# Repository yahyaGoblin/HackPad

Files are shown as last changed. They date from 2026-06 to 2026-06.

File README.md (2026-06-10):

# HACKPAD
A compact 4-key macropad powered by the Seeed XIAO, with a rotary encoder for volume, scroll, or whatever feels useful that week. Fully custom PCB, hand-routed, with MX-compatible switch footprints at 19.05mm spacing.
This was the project that started everything — a Hack Club Hackpad build that turned into a crash course in KiCad, footprint libraries, PCB layout, and knowing when to scale back (and when not to). It taught the fundamentals that every later project relied on.

### Schematic Preview


### PCB Preview


### 3D Model


## Features
- 4 mechanical key switches
- 1 rotary encoder (clicky, EC11)
- Seeed XIAO MCU (small footprint, USB-C)
- Compact single PCB design

### Bill of Materials
| Component | Part | Quantity | Notes | Link | Distributor |
|---|---|---|---|---|---|
| Microcontroller | Seeed XIAO RP2040 | 1 | | [Link](https://keebd.com/products/xiao-rp2040-controller?_pos=1&_psq=xiao&_ss=e&_v=1.0) | KEEBD |
| Switches | MX-compatible mechanical switches (Gateron Blue) | 4 | 5-pin or 3-pin | [Link](https://keebd.com/products/gateron-blue) | KEEBD |
| Keycaps | MX keycaps | 4 | | — | local |
| Rotary Encoder | EC11 rotary encoder | 1 | With push switch | [Link](https://keebd.com/products/ec11-encoder-with-switch?_pos=1&_psq=enco&_ss=e&_v=1.0) | KEEBD |
| Encoder Knob | 3D Printed EC11-compatible knob | 1 | | [Link](https://keebd.com/products/3d-printed-encoder-knob?variant=40383061917848) | KEEBD |
| PCB | Custom (this repo) | 1 | Gerbers in `/gerbers` | — | PCBWay |
| Baseplate | Laser cut / 3D printed | 1 | Holds the PCB | — | local |
| USB Cable | USB-C | 1 | | — | local |

---


## Fabrication
Gerber files are in the `/gerbers` folder, ready to send to JLCPCB, PCBWay, or your preferred fab.

## Firmware
Designed for use with [KMK](https://github.com/KMKfw/kmk_firmware). See `code.py` for the full config — 4 keys mapped to media controls, encoder for volume with mute on press.

## License
Open source hardware — feel free to modify and build your own.

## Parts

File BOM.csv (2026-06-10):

Name | Purpose | QTY | Total (USD) | Link | Distributor
Baseplate | Holding the PCB | 1 | $3.00 | - | local
PCB | PCB | 1 | $5.00 | - | PCBWay
Encoder Knob | Knob for rotary encoder | 1 | $2.51 | https://keebd.com/products/3d-printed-encoder-knob?variant=40383061917848 | KEEBD
Seeed XIAO RP2040 | Main microcontroller | 1 | $9.70 | https://keebd.com/products/xiao-rp2040-controller?_pos=1&_psq=xiao&_ss=e&_v=1.0 | KEEBD
EC11 Rotary Encoder (clicky) | Rotary input with push button — SW7 | 1 | $3.23 | https://keebd.com/products/ec11-encoder-with-switch?_pos=1&_psq=enco&_ss=e&_v=1.0 | KEEBD
Cherry MX Compatible Switches (Gateron Blue) | Key input | 1 | $3.23 | https://keebd.com/products/gateron-blue | KEEBD

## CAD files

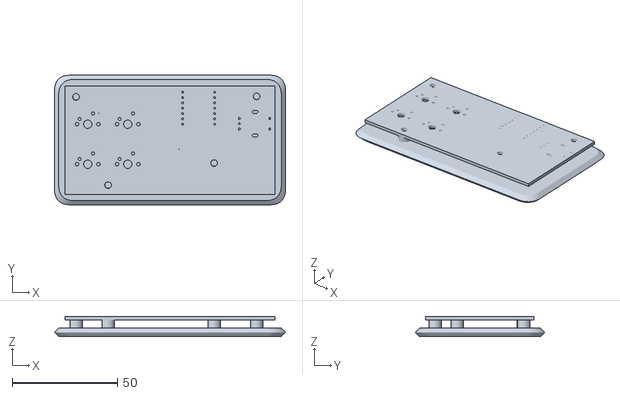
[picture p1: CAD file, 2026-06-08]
BasePlate CAD/HackPadAssembly.stl
110.0 x 61.7 x 9.59

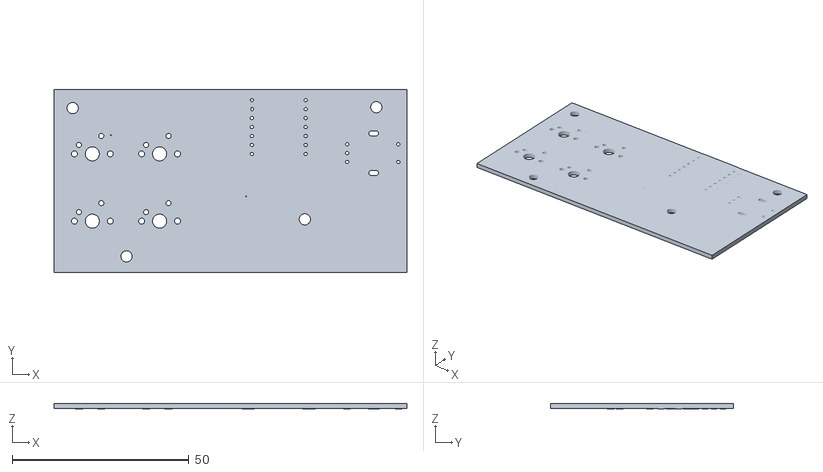
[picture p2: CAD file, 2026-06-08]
HackPad/hackpad.stl
100.0 x 51.7 x 1.62

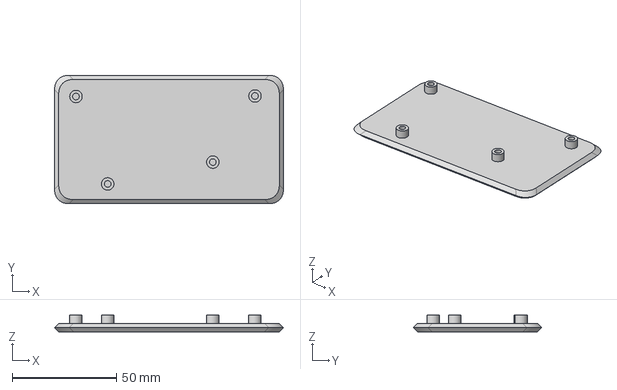
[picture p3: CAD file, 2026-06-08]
BasePlate CAD/HackPad.step
110.0 x 61.7 x 8.00 mm

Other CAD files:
BasePlate CAD/HackPad.stl

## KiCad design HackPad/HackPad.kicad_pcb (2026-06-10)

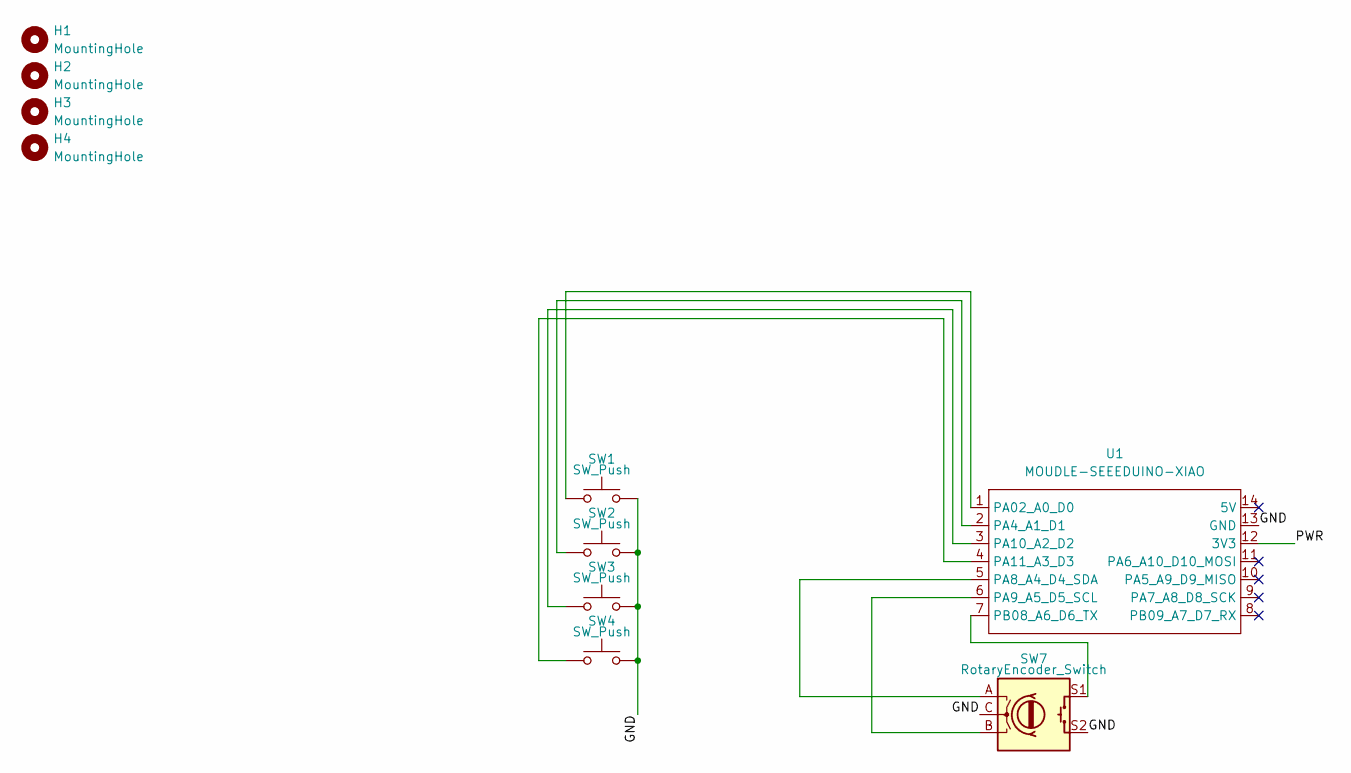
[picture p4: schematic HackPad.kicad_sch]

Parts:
H1, H2, H3, H4: MountingHole; MountingHole_3.2mm_M3
SW1, SW2, SW3, SW4: SW_Push; SW_Cherry_MX_1.00u_PCB
SW7: RotaryEncoder_Switch; RotaryEncoder_Alps_EC11E-Switch_Vertical_H20mm
U1: MOUDLE-SEEEDUINO-XIAO; XIAO-Generic-Hybrid-14P-2.54-21X17.8MM

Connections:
/GND: SW1.2, SW2.2, SW3.2, SW4.2, SW7.C, SW7.S2, U1.13 (GND)
/PWR: U1.12 (3V3)
unnamed: SW1.1, U1.1 (PA02_A0_D0)
unnamed: SW2.1, U1.2 (PA4_A1_D1)
unnamed: SW7.A, U1.5 (PA8_A4_D4_SDA)
unnamed: SW7.B, U1.6 (PA9_A5_D5_SCL)
unnamed: SW3.1, U1.3 (PA10_A2_D2)
unnamed: SW4.1, U1.4 (PA11_A3_D3)
unnamed: SW7.S1, U1.7 (PB08_A6_D6_TX)

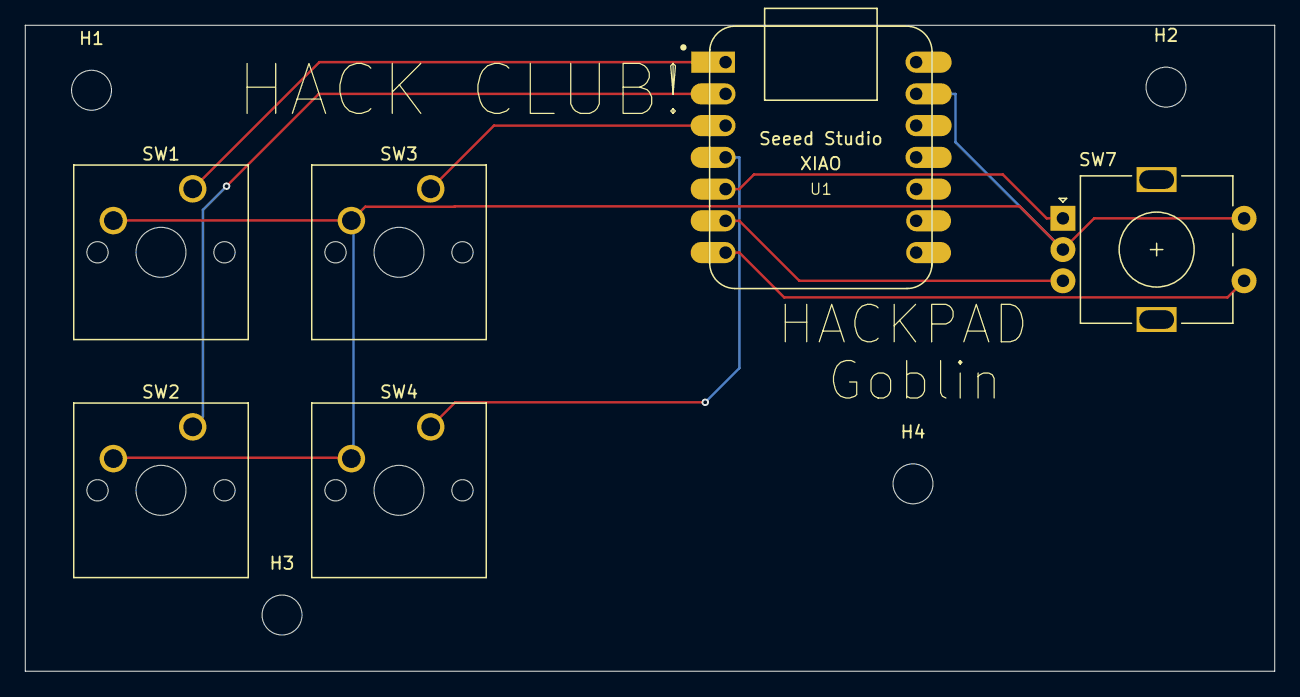
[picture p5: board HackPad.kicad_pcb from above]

Board: 2 copper layers, 100.0 x 51.7 mm, 10 parts (0 on the bottom side), 8 nets.

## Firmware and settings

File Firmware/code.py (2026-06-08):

import board
from kmk.kmk_keyboard import KMKKeyboard
from kmk.keys import KC
from kmk.modules.encoder import EncoderHandler
from kmk.scanners.keypad import KeysScanner

keyboard = KMKKeyboard()

# ── Keys (4 direct-wired switches) ───────────────────────────────────────────
keyboard.matrix = KeysScanner(
    pins=[
        board.D0,  # SW1
        board.D1,  # SW2
        board.D2,  # SW3
        board.D3,  # SW4
    ],
    value_when_pressed=False,  # keys pull to GND
    pull=True,
)

# ── Encoder (SW7 only — clicky) ───────────────────────────────────────────────
encoder_handler = EncoderHandler()

encoder_handler.pins = (
    # (CLK/A,   DT/B,     SW,       is_inverted)
    (board.D4, board.D5, board.D6, False),  # SW7 — clicky encoder
)

keyboard.modules.append(encoder_handler)

# ── Keymap ────────────────────────────────────────────────────────────────────
# Key order: SW1, SW2, SW3, SW4
keyboard.keymap = [
    [
        KC.MPLY,  # SW1 — Play/Pause
        KC.MPRV,  # SW2 — Previous track
        KC.MNXT,  # SW3 — Next track
        KC.MUTE,  # SW4 — Mute
    ]
]

# Encoder actions per layer: (CW, CCW, press)
# SW7: CW = Vol↑, CCW = Vol↓, press = Mute
encoder_handler.map = [
    (
        (KC.VOLU, KC.VOLD, KC.MUTE),  # SW7 layer 0
    ),
]

# ── Go! ───────────────────────────────────────────────────────────────────────
if __name__ == '__main__':
    keyboard.go()

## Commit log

2026-05-26 Revise README with updated project details
    Updated project description, features, and bill of materials to reflect changes in components and design.
2026-05-26 Revise image formatting for schematic and PCB previews
    Updated image sections for schematic and PCB previews in README.
2026-06-08 Revise README for 4-key macropad specifications
    Updated the project description, features, and bill of materials to reflect changes in the macropad design and components.
2026-06-08 final build with updated code and schematics
    [HackPad.kicad_pcb, HackPad.kicad_sch]
2026-06-08 updated gerbers
    [HackPad-B_Cu.gbr, HackPad-B_Mask.gbr, HackPad-B_Paste.gbr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]
2026-06-08 step file
    [.step, HackPad.step, hackpad.step]
2026-06-08 final assembly
    [.step, HackPadAssembly.stl, hackpad.step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]
2026-06-10 Add Bill of Materials to README
    Added Bill of Materials section with detailed components and links.
2026-06-10 BOM upload
    [BOM.csv]
